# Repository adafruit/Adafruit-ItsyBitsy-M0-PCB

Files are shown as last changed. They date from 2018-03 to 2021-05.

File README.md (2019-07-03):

## Adafruit ItsyBitsy M0 microcontroller breakout PCB

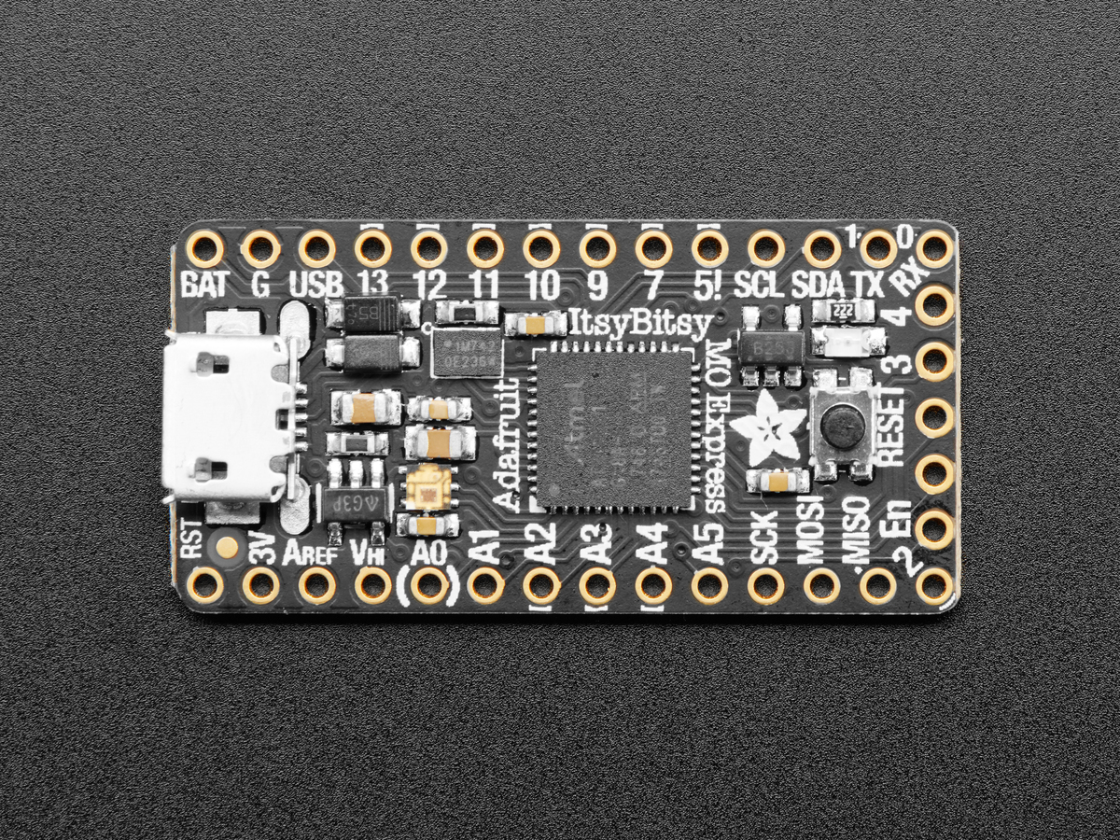
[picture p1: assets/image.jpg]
<a href="http://www.adafruit.com/products/3727"><br/>
Click here to purchase one from the Adafruit shop</a>

PCB files for the Adafruit ItsyBitsy M0. PCB format is EagleCAD schematic and board layout

For more details, check out the product pages at
* https://www.adafruit.com/products/3727

### Description

What's smaller than a Feather but larger than a Trinket? It's an Adafruit ItsyBitsy M0 Express! Small, powerful, with a rockin' ATSAMD21 Cortex M0 processor running at 48 MHz - this microcontroller board is perfect when you want something very compact, but still with a bunch of pins.

ItsyBitsy M0 Express is only 1.4" long by 0.7" wide, but has 6 power pins, 23 digital GPIO pins (12 of which can be analog in, 1x analog out, and 13x PWM out). It's the same chip as the Arduino Zero and packs much of the same capability as an Adafruit Metro M0 Express or Feather M0 Express but really really small. So it's great once you've finished up a prototype on a Metro M0 or Feather M0, and want to make the project much smaller. It even comes with 2MB of SPI Flash built in, for data logging, file storage, or CircuitPython code.

The most exciting part of the ItsyBitsy M0 is that while you can use it with the Arduino IDE, we are shipping it with CircuitPython on board. When you plug it in, it will show up as a very small disk drive with main.py on it. Edit main.py with your favorite text editor to build your project using Python, the most popular programming language. No installs, IDE or compiler needed, so you can use it on any computer, even ChromeBooks or computers you can't install software on. When you're done, unplug the Itsy' and your code will go with you.

### License

Adafruit invests time and resources providing this open source design, please support Adafruit and open-source hardware by purchasing products from [Adafruit](https://www.adafruit.com)!

Designed by Limor Fried/Ladyada for Adafruit Industries.

Creative Commons Attribution/Share-Alike, all text above must be included in any redistribution. See license.txt for additional details.

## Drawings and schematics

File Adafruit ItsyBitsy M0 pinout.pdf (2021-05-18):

# Itsy Bitsy M0 Express

## https://www.adafruit.com/product/3727

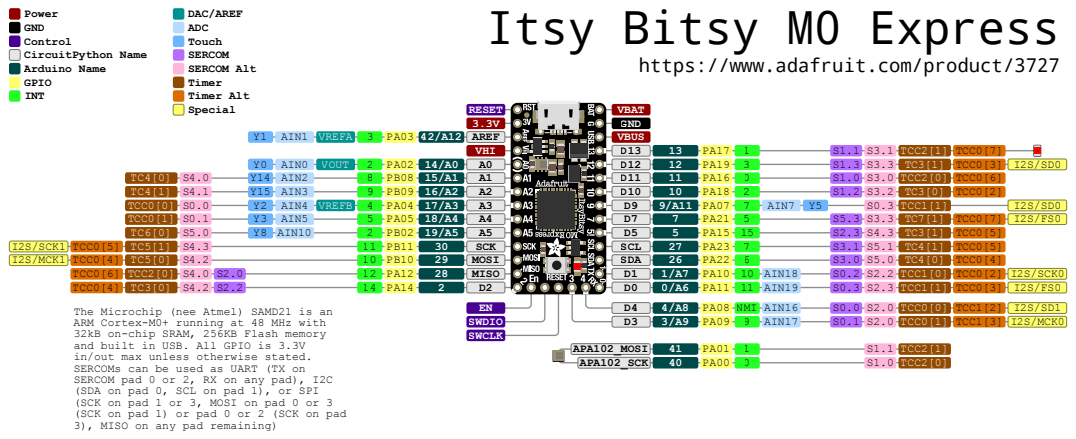
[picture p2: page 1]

The Microchip (nee Atmel) SAMD21 is an
ARM Cortex-M0+ running at 48 MHz with
32kB on-chip SRAM, 256KB Flash memory
and built in USB. All GPIO is 3.3V
in/out max unless otherwise stated.
SERCOMs can be used as UART (TX on
SERCOM pad 0 or 2, RX on any pad), I2C
(SDA on pad 0, SCL on pad 1), or SPI
(SCK on pad 1 or 3, MOSI on pad 0 or 3
(SCK on pad 1) or pad 0 or 2 (SCK on pad
3), MISO on any pad remaining)

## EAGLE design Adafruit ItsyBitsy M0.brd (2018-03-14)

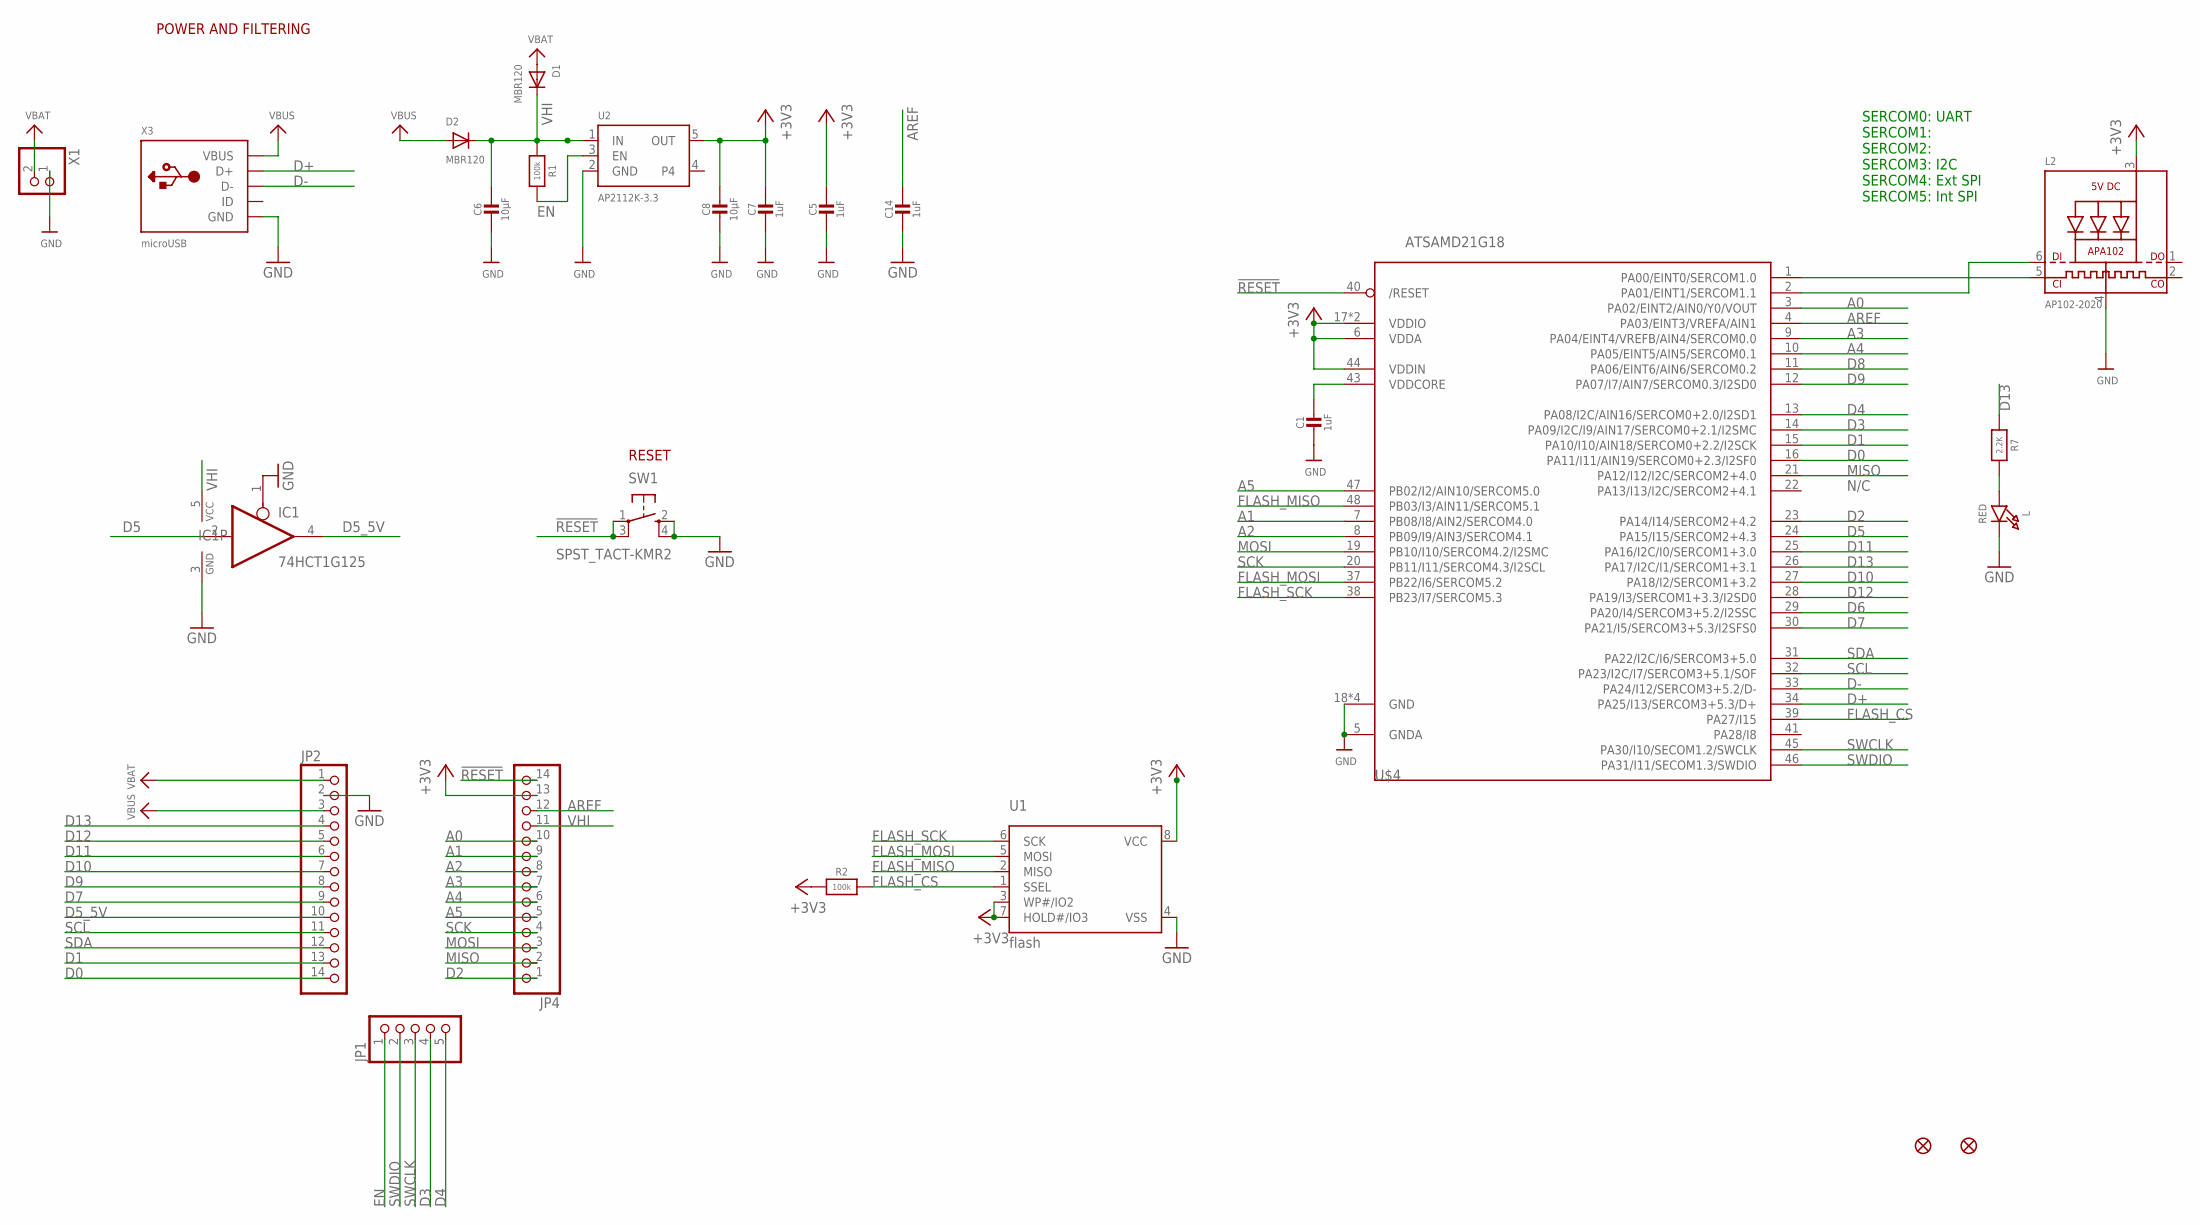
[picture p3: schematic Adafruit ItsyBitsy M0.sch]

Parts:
C1, C5, C7, C14: 1uF; 0603-NO
C6, C8: 10µF; 0805-NO
D1, D2: MBR120; SOD-123FL
IC1: 74HCT1G125; SOT23-5
JP1: HEADER-1X570MIL; 1X05_ROUND_70
JP2, JP4: HEADER-1X14; 1X14_ROUND70
L: RED; CHIPLED_0805_NOOUTLINE
L2: AP102-2020; APA102_2020
R1, R2: 100k; 0603-NO
R7: 2.2K; 0603-NO
SW1: SPST_TACT-KMR2; KMR2
U1: flash; USON8
U2: AP2112K-3.3; SOT23-5
U$4: ATSAMD21G18; TQFN48_7MM
U$34, U$35: FIDUCIAL_1MM
X1: CON_JST_PH_2PIN; JSTPH2
X3: microUSB; 4UCONN_20329_V2

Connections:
!RESET: JP4.14, SW1.1, SW1.3 (P1), U$4.40 (/RESET)
+3V3: C5.1, C7.1, C8.1, JP4.13, L2.3 (VDD), R2.1, U1.3 (WP#/IO2), U1.7 (HOLD#/IO3), U1.8 (VCC), U2.5 (OUT), U$4.6 (VDDA), U$4.17 (VDDIO), U$4.36 (VDDIO), U$4.44 (VDDIN)
A0: JP4.10, U$4.3 (PA02/EINT2/AIN0/Y0/VOUT)
A1: JP4.9, U$4.7 (PB08/I8/AIN2/SERCOM4.0)
A2: JP4.8, U$4.8 (PB09/I9/AIN3/SERCOM4.1)
A3: JP4.7, U$4.9 (PA04/EINT4/VREFB/AIN4/SERCOM0.0)
A4: JP4.6, U$4.10 (PA05/EINT5/AIN5/SERCOM0.1)
A5: JP4.5, U$4.47 (PB02/I2/AIN10/SERCOM5.0)
AREF: C14.1, JP4.12, U$4.4 (PA03/EINT3/VREFA/AIN1)
D0: JP2.14, U$4.16 (PA11/I11/AIN19/SERCOM0+2.3/I2SF0)
D1: JP2.13, U$4.15 (PA10/I10/AIN18/SERCOM0+2.2/I2SCK)
D2: JP4.1, U$4.23 (PA14/I14/SERCOM2+4.2)
D3: JP1.4, U$4.14 (PA09/I2C/I9/AIN17/SERCOM0+2.1/I2SMC)
D4: JP1.5, U$4.13 (PA08/I2C/AIN16/SERCOM0+2.0/I2SD1)
D5: IC1.2 (I), U$4.24 (PA15/I15/SERCOM2+4.3)
D5_5V: IC1.4 (O), JP2.10
D6: U$4.29 (PA20/I4/SERCOM3+5.2/I2SSC)
D7: JP2.9, U$4.30 (PA21/I5/SERCOM3+5.3/I2SFS0)
D8: U$4.11 (PA06/EINT6/AIN6/SERCOM0.2)
D9: JP2.8, U$4.12 (PA07/I7/AIN7/SERCOM0.3/I2SD0)
D10: JP2.7, U$4.27 (PA18/I2/SERCOM1+3.2)
D11: JP2.6, U$4.25 (PA16/I2C/I0/SERCOM1+3.0)
D12: JP2.5, U$4.28 (PA19/I3/SERCOM1+3.3/I2SD0)
D13: JP2.4, R7.1, U$4.26 (PA17/I2C/I1/SERCOM1+3.1)
D+: U$4.34 (PA25/I13/SERCOM3+5.3/D+), X3.D+
D-: U$4.33 (PA24/I12/SERCOM3+5.2/D-), X3.D-
EN: JP1.1, R1.2, U2.3 (EN)
FLASH_CS: R2.2, U1.1 (SSEL), U$4.39 (PA27/I15)
FLASH_MISO: U1.2 (MISO), U$4.48 (PB03/I3/AIN11/SERCOM5.1)
FLASH_MOSI: U1.5 (MOSI), U$4.37 (PB22/I6/SERCOM5.2)
FLASH_SCK: U1.6 (SCK), U$4.38 (PB23/I7/SERCOM5.3)
GND: C1.2, C5.2, C6.2, C7.2, C8.2, C14.2, IC1.1 (OE), IC1.3 (GND), JP2.2, L.C, L2.4 (GND), SW1.2 (S), SW1.4 (S1), U1.4 (VSS), U2.2 (GND), U$4.5 (GNDA), U$4.18 (GND), U$4.35 (GND), U$4.42 (GND), U$4.THERMAL (GND), X1.1, X3.BASE@1 (GND), X3.BASE@2 (GND), X3.GND, X3.SPRT@1 (GND), X3.SPRT@2 (GND), X3.SPRT@3 (GND), X3.SPRT@4 (GND)
MISO: JP4.2, U$4.21 (PA12/I12/I2C/SERCOM2+4.0)
MOSI: JP4.3, U$4.19 (PB10/I10/SERCOM4.2/I2SMC)
unnamed: L2.5 (CKI), U$4.1 (PA00/EINT0/SERCOM1.0)
unnamed: L.A, R7.2
unnamed: L2.6 (DI), U$4.2 (PA01/EINT1/SERCOM1.1)
SCK: JP4.4, U$4.20 (PB11/I11/SERCOM4.3/I2SCL)
SCL: JP2.11, U$4.32 (PA23/I2C/I7/SERCOM3+5.1/SOF)
SDA: JP2.12, U$4.31 (PA22/I2C/I6/SERCOM3+5.0)
SWCLK: JP1.3, U$4.45 (PA30/I10/SECOM1.2/SWCLK)
SWDIO: JP1.2, U$4.46 (PA31/I11/SECOM1.3/SWDIO)
VBAT: D1.A, JP2.1, X1.2
VBUS: D2.A, JP2.3, X3.VBUS
VDDCORE: C1.1, U$4.43 (VDDCORE)
VHI: C6.1, D1.C, D2.C, IC1.5 (VCC), JP4.11, R1.1, U2.1 (IN)

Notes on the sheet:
POWER AND FILTERING
RESET
N/C
SERCOM0: UART SERCOM1: SERCOM2: SERCOM3: I2C SERCOM4: Ext SPI SERCOM5: Int SPI

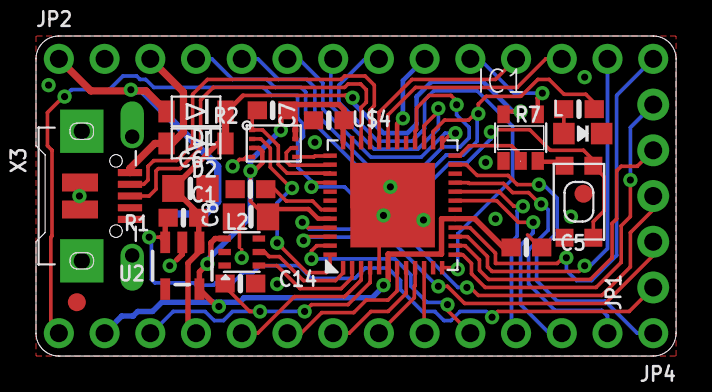
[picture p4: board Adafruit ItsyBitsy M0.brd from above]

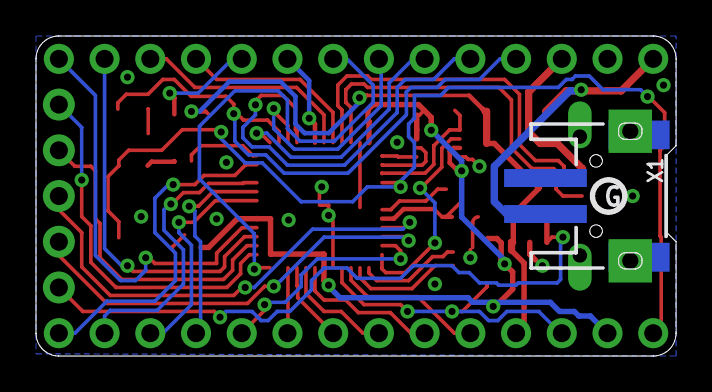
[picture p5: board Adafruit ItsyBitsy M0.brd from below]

Board: 2 copper layers, 35.6 x 17.8 mm, 28 parts (3 on the bottom side), 44 nets.

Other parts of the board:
U$13: PCBFEAT-REV-040
U$14: ITSYM0_TOP
U$15: ITSYM0_BOT

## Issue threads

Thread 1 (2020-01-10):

Missing traces in .brd file?

smarpug, 2020-01-10:

Closed 2020-01-10.

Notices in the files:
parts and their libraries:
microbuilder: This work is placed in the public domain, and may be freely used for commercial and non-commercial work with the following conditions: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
